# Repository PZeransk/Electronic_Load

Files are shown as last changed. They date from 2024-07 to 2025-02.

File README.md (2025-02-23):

# Electronic_Load

The aim of this project is to design high power (around 200W) electronic load. It will be developed on STM32 uC. Whole repository will feature electronic schematic, PCB and code.

### Used external libralies
https://github.com/afiskon/stm32-ssd1306

### Current problems

I have encoutered two issues with my PCB design:
* Wrong D4 pinout, pins are mixed so diode does not conduct any current 
* Nucleo connectors are moved 2.54 mm to the side

Both will be fixed in another PCB revision.

### Differences between schematic and PCB

To ease further prototyping I made following changes:
* Instead of 4 1 Ohm resistor I used one 12 Ohm to lower the maximum current,
* Used only one NMOS, that is because the current will be lower now and if something breaks, it will be cheaper to replace,
* Shorted every potentiometer, they are supposed to be used for voltage compensation, but during this stage of prototyping they will be useless,
* In place of D4 I used random 1N4007 diode to keep reverse polarity protection,
* Removed eFuse, because it didn't work correctly (I hope Murphy didn't get it).

Changes may be obsereved on the photo below.

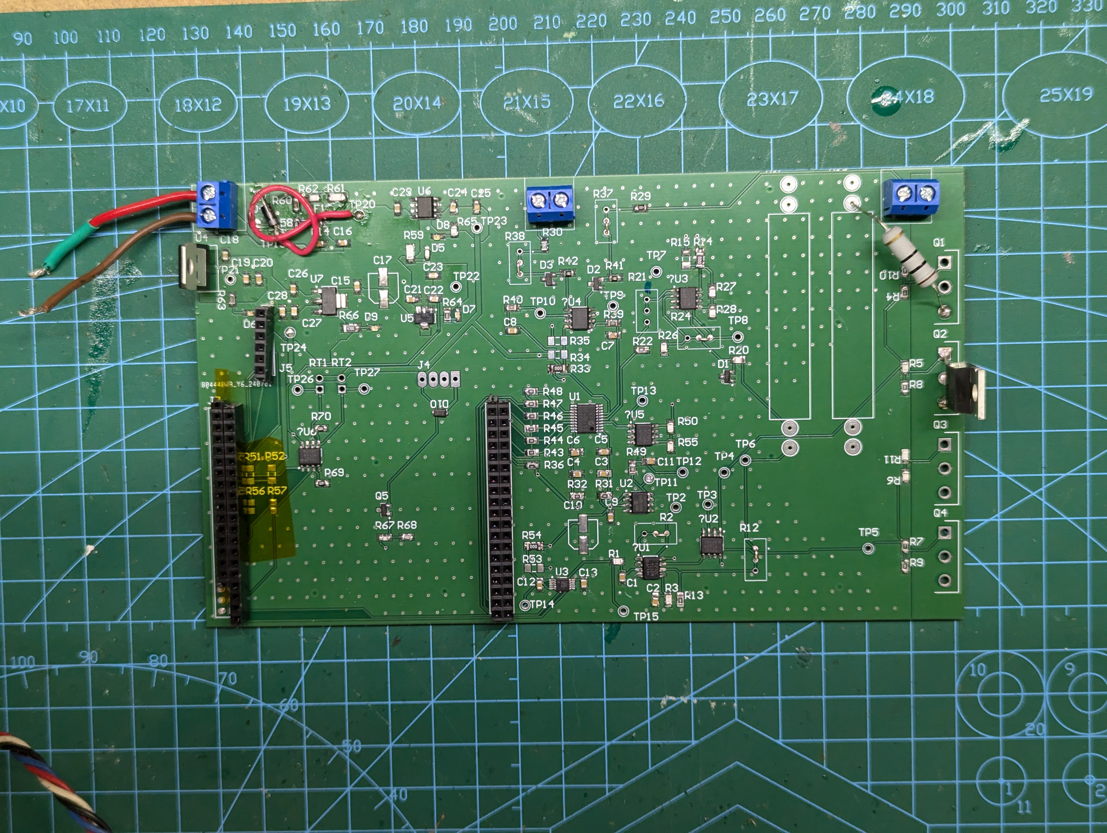
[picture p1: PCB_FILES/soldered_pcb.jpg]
Soldered PCB photo


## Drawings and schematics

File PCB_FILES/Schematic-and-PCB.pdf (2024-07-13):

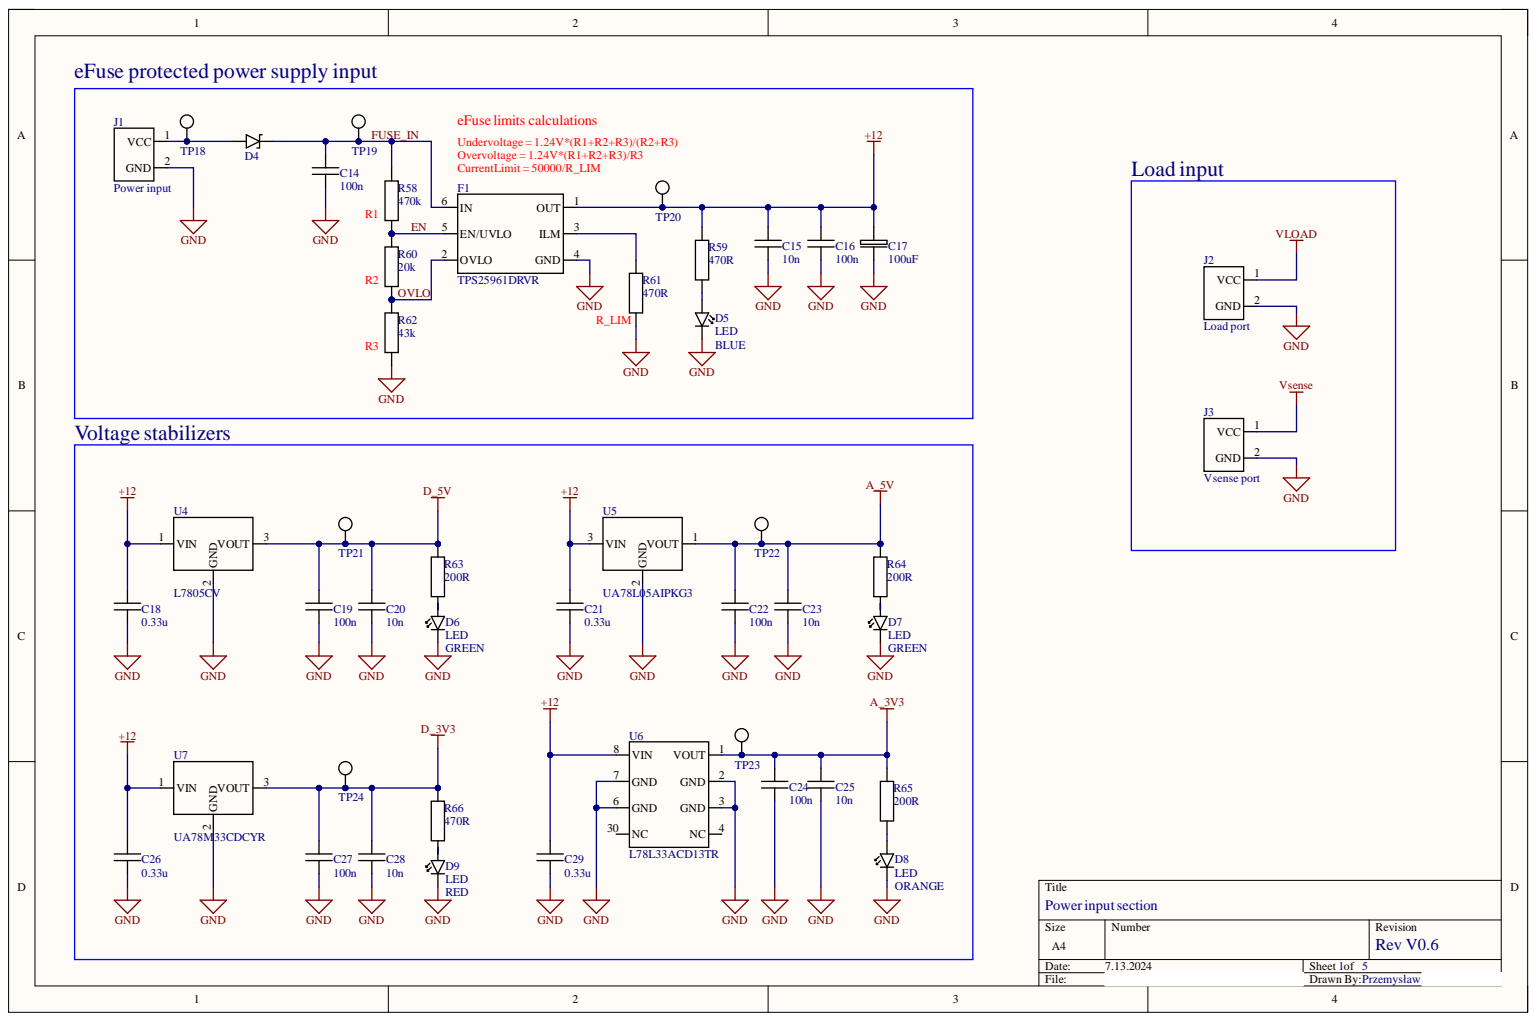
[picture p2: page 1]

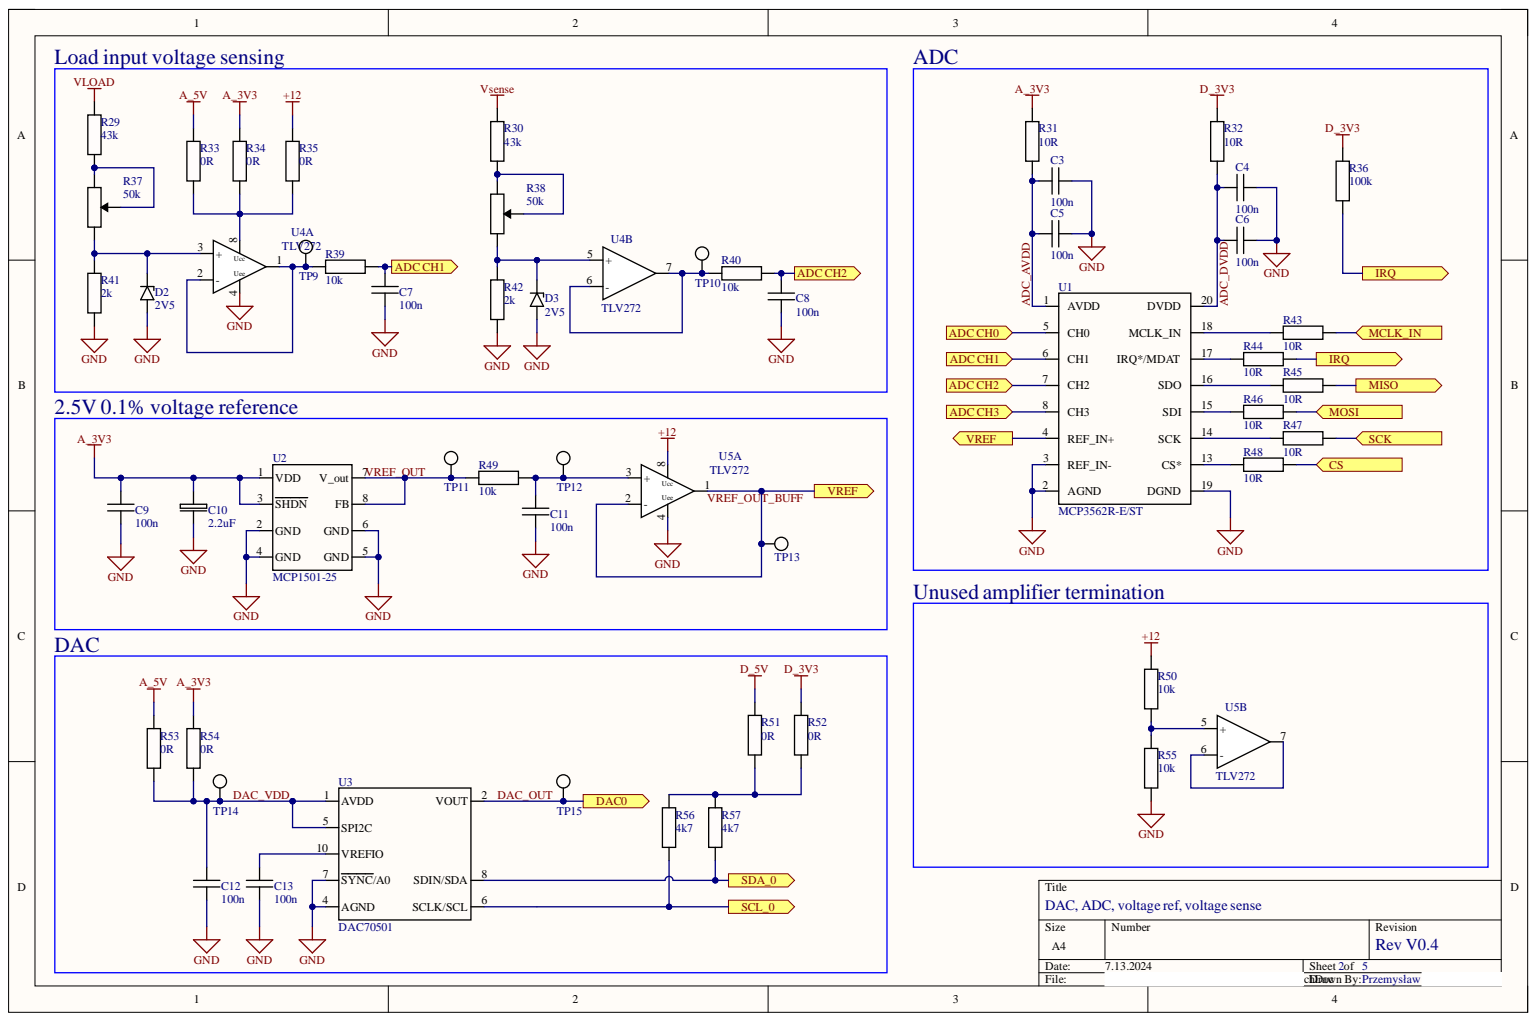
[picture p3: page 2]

Title
DAC, ADC, voltage ref, voltage sense

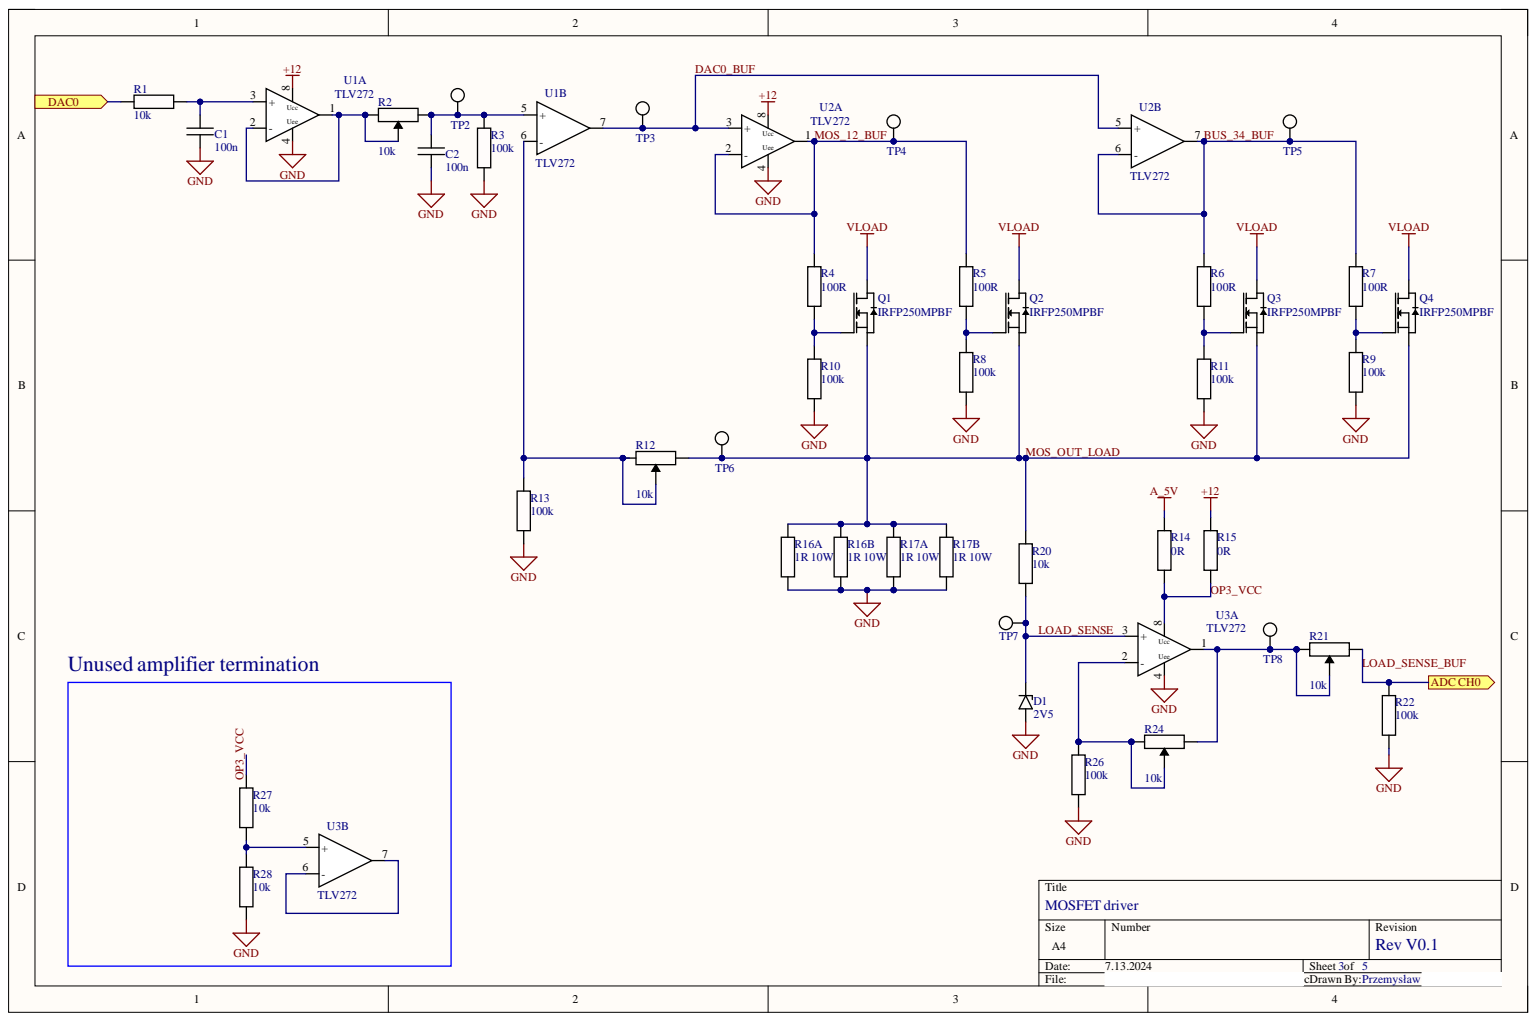
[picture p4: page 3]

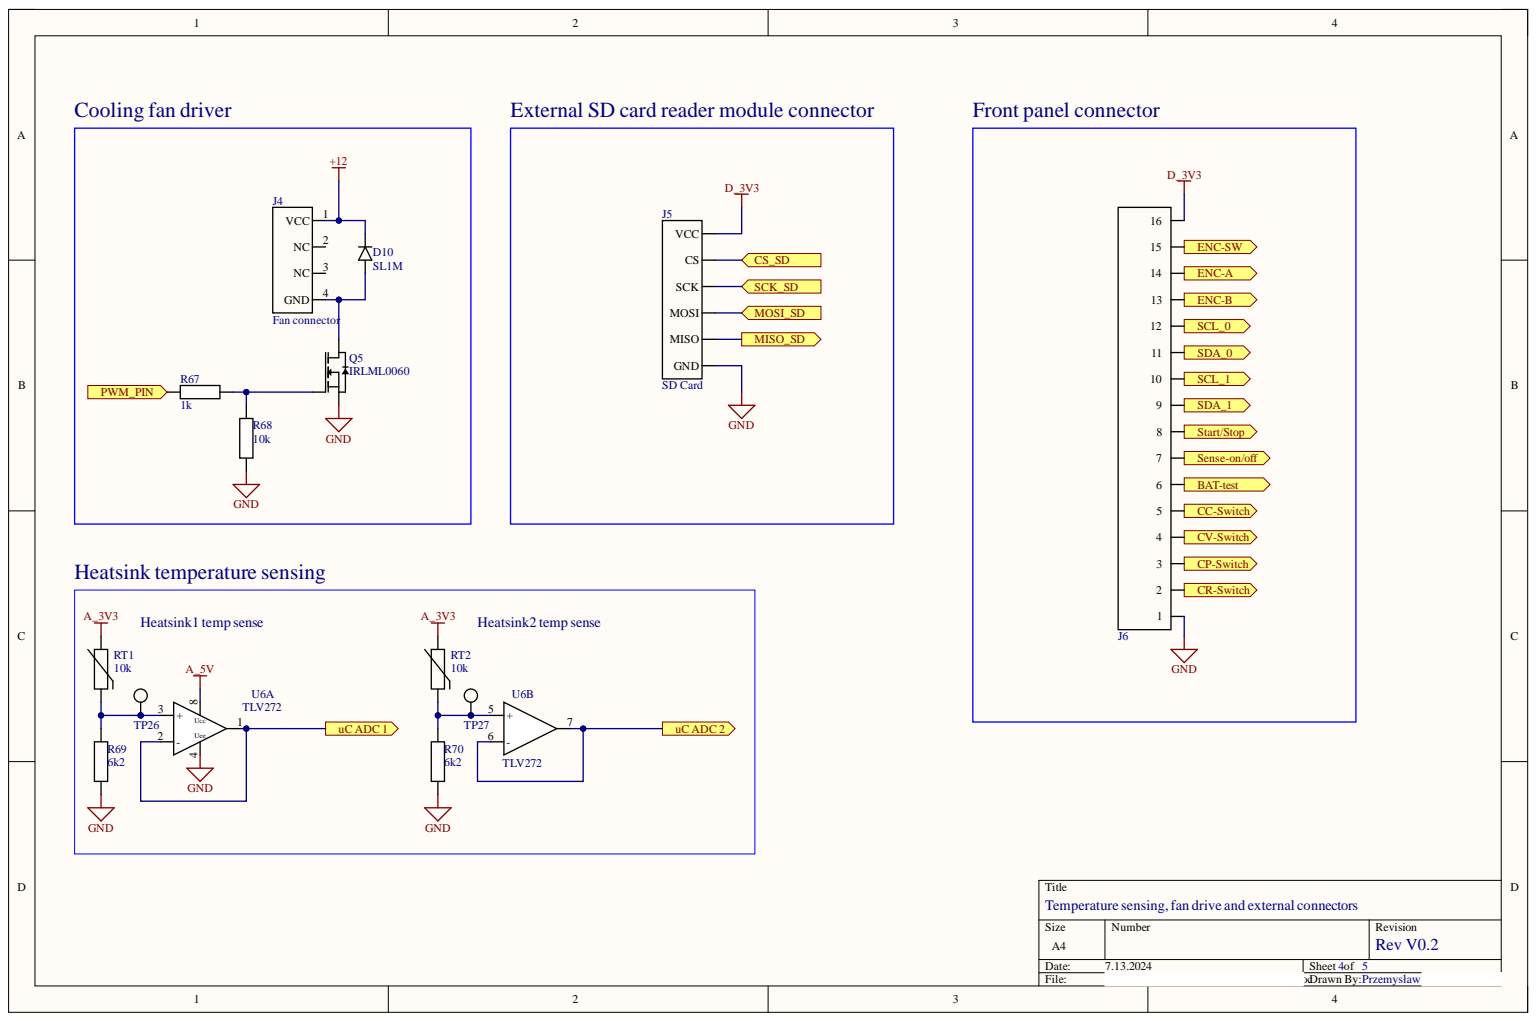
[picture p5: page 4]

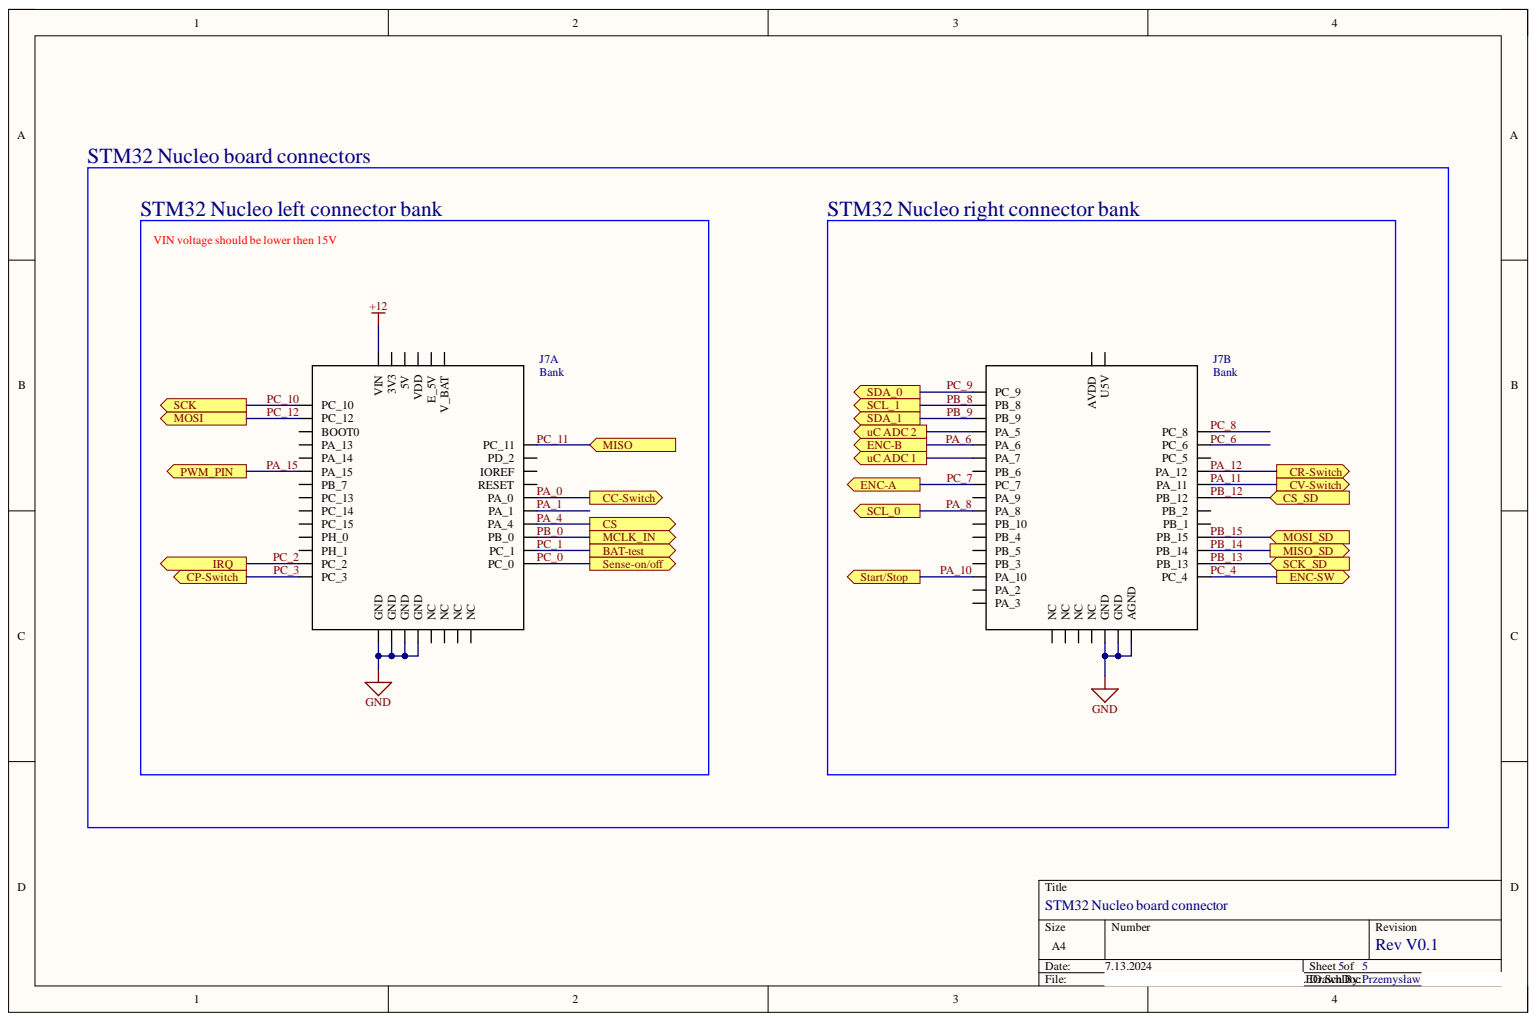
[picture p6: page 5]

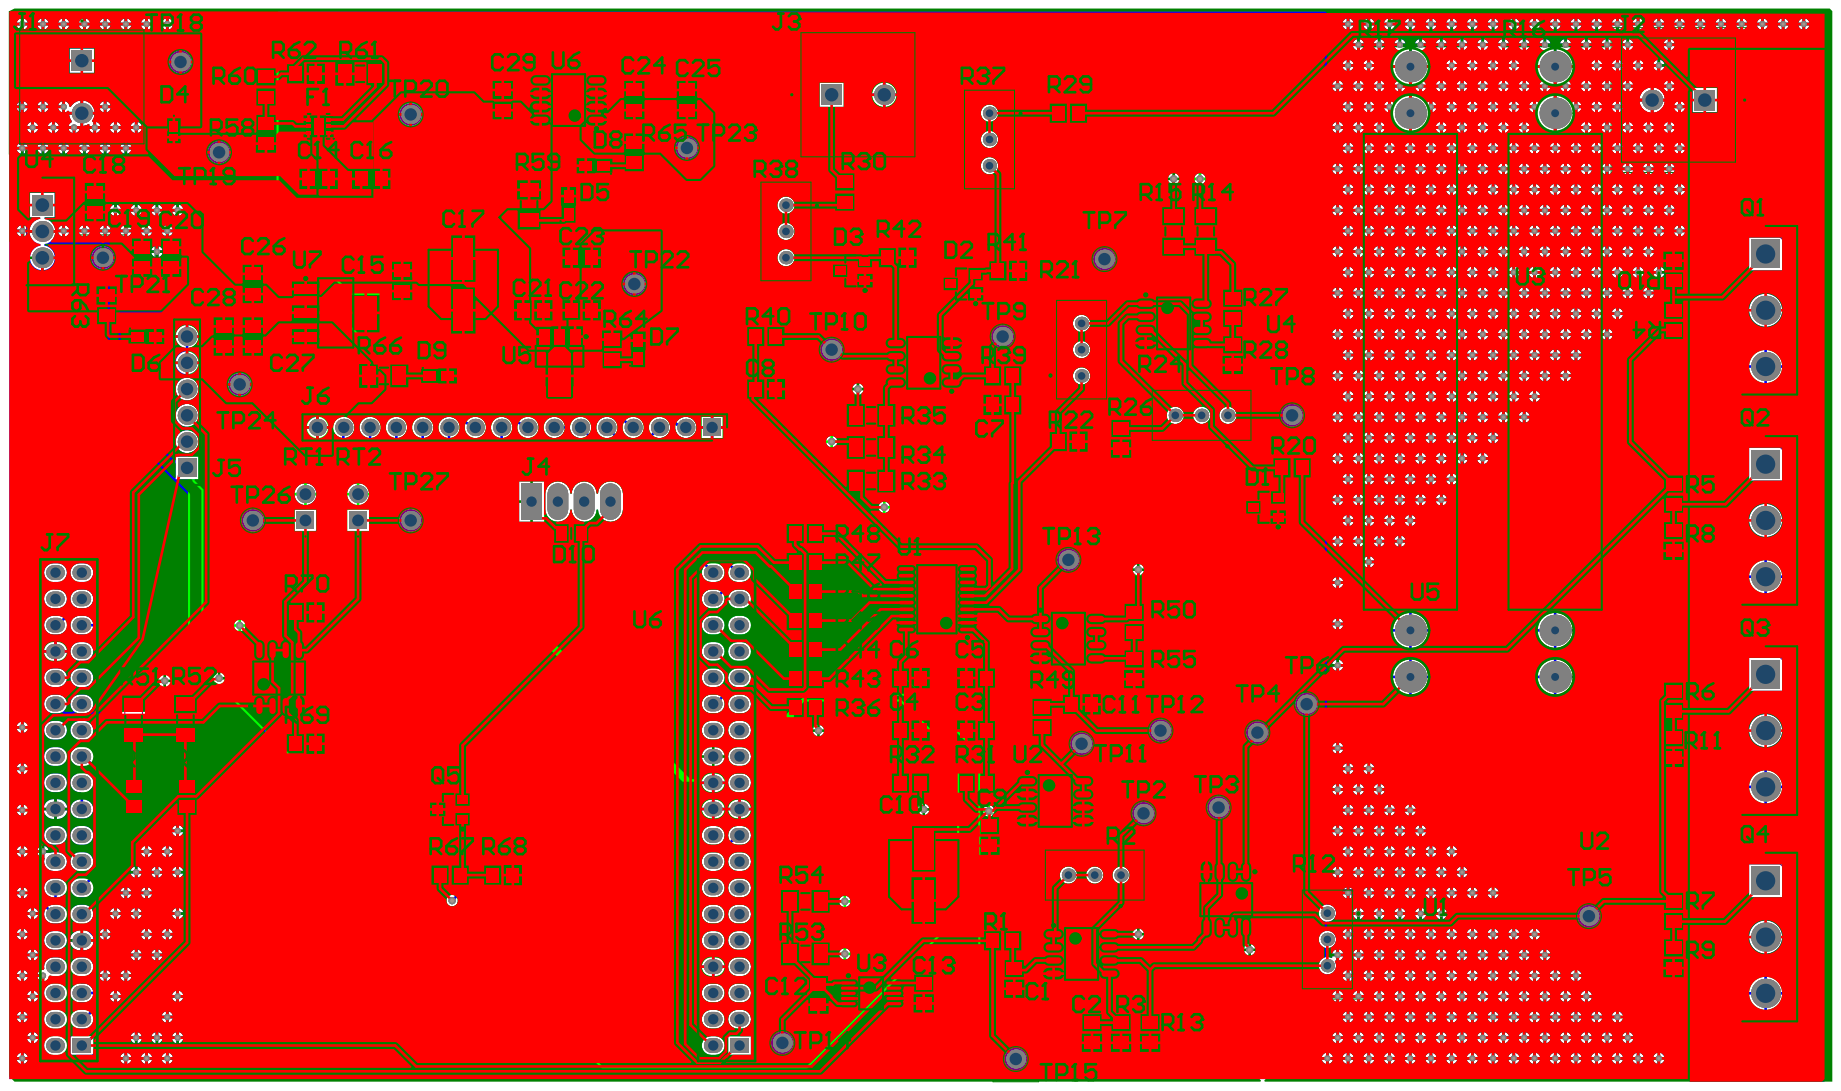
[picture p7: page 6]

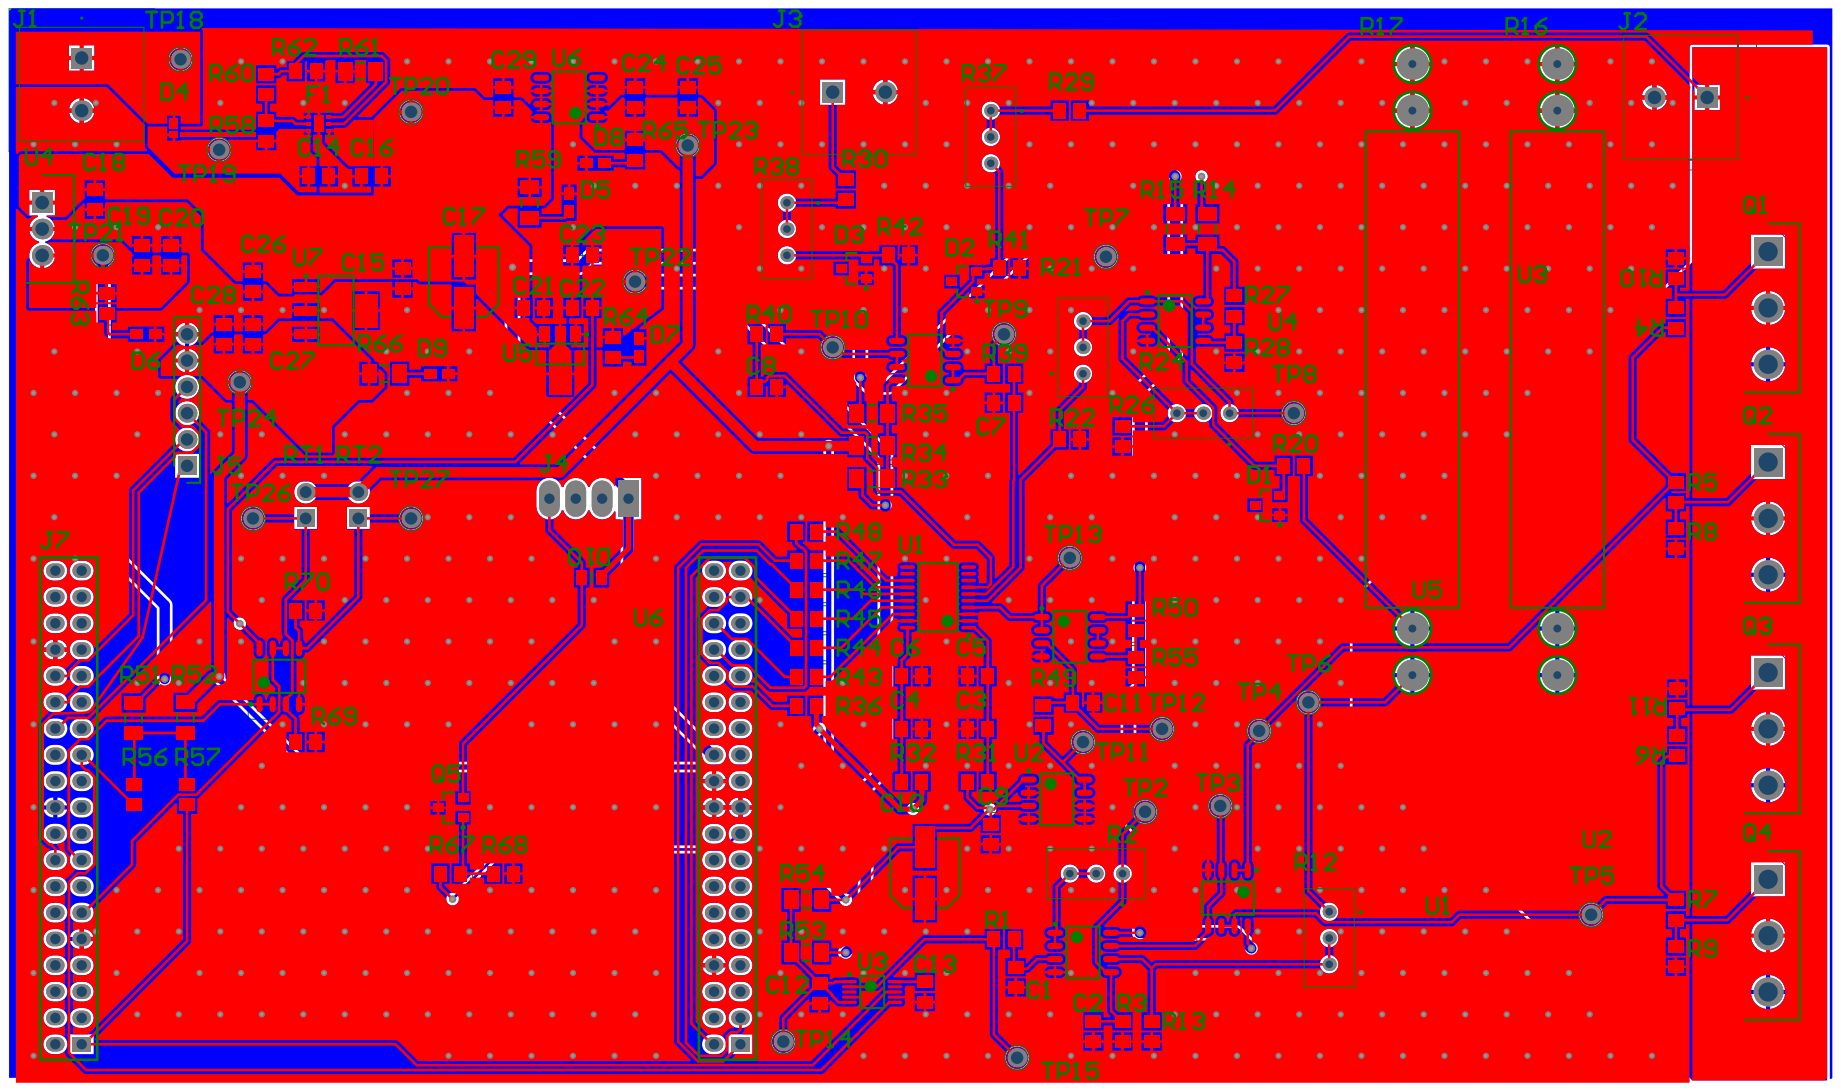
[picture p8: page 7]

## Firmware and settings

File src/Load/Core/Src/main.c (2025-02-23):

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
/* Includes ------------------------------------------------------------------*/
#include "main.h"
#include "adc.h"
#include "dma.h"
#include "i2c.h"
#include "spi.h"
#include "tim.h"
#include "usart.h"
#include "gpio.h"

/* USER CODE BEGIN Includes */
#include "menu.h"
#include "functions.h"
#include "DAC70501.h"
/* USER CODE END Includes */

/* USER CODE BEGIN PD */
#define menuCount 3
/* USER CODE END PD */


/* USER CODE BEGIN PV */
I2C_HandleTypeDef hi2c1;
uint8_t pulses = 0;
uint8_t positions = 0;
/* USER CODE END PV */

void SystemClock_Config(void);
/* USER CODE BEGIN 0 */

// define menus
menu CCMenu;
menu CVMenu;
menu CPMenu;
menu CRMenu;
menu BatMenu;


menu menuArray[menuCount]; // there are 4 menus

uint8_t toggles = 0;
uint8_t modToggles = 0;
uint8_t encToggles = 0;
uint8_t setPosition = 0;
uint8_t changeSetToggles = 0;

uint8_t arraySize=0;
bool wasToggled = false;
bool startStop = false;
bool setMode = false;


/* USER CODE END 0 */

/**
  * @brief  The application entry point.
  * @retval int
  */
int main(void)
{
  /* MCU Configuration--------------------------------------------------------*/

  /* Reset of all peripherals, Initializes the Flash interface and the Systick. */
  HAL_Init();

  /* Configure the system clock */
  SystemClock_Config();

  /* Initialize all configured peripherals */
  MX_GPIO_Init();
  MX_USART2_UART_Init();
  MX_I2C1_Init();
  MX_SPI2_Init();
  MX_DMA_Init();
  MX_TIM1_Init();
  MX_TIM3_Init();
  MX_ADC1_Init();
  MX_I2C3_Init();
  MX_SPI3_Init();
  /* USER CODE BEGIN 2 */

  HAL_TIM_Encoder_Start(&htim3, TIM_CHANNEL_ALL);

  ssd1306_Init();
  ssd1306_SetCursor(8, 10);
  ssd1306_WriteString("ELECTRTONIC LOAD", Font_7x10, White);
  ssd1306_SetCursor(14, 20);
  ssd1306_WriteString("Ver. V0.0", Font_11x18, White);
  ssd1306_SetCursor(46, 38);
  ssd1306_WriteString("Author", Font_6x8, White);
  ssd1306_SetCursor(40, 46);
  ssd1306_WriteString("PZERANSK", Font_6x8, White);
  ssd1306_UpdateScreen();

  //ssd1306_Fill(Black);
  initStruct(&CCMenu, "CC Mode", "Set I:", "U in:", "Power:");
  initStruct(&CVMenu, "CV Mode", "Set U:", "Power:", "I in:");
  initStruct(&CPMenu, "CP Mode", "Set P:", "Power:", "x");
  initStruct(&CRMenu, "CR Mode", "Set R:", "Power:", "x");
  initStruct(&BatMenu, "BAT Test", "Set I:", "Set U", "Capacity");
  menuArray[0]=CCMenu;
  menuArray[1]=CPMenu;
  menuArray[2]=BatMenu;
  //menuArray[2]=CVMenu;
  //menuArray[3]=CRMenu;
  strcpy(menuArray[0].val_line1,"01000");
  strcpy( menuArray[1].val_line1,"010");
  HAL_Delay(2000);
  //displayMenu(&CCMenu);



  /* USER CODE END 2 */

  /* Infinite loop */
  /* USER CODE BEGIN WHILE */

  while (1)
  {
    ssd1306_Fill(Black);

    checkLongPress(GPIOC, SET_Mode_Pin, &setMode, &changeSetToggles);

	modToggles = toggles%menuCount;
	menuArray[modToggles].status = startStop;
	pulses = TIM3->CNT;
	positions = pulses/2;
	if(setMode){
		if(strncmp(menuArray[modToggles].measVal1,"Set x:",4)==0){

			if(changeSetToggles%2==0){

				arraySize = sizeof(menuArray[modToggles].val_line1)/sizeof(*menuArray[modToggles].val_line1);
				setPosition = encToggles%(arraySize);
				ssd1306_Line(42+7*setPosition, 28, 42+7*setPosition+7, 28, White);
				menuArray[modToggles].val_line1[setPosition] = positions%10+'0';

			}else if(changeSetToggles%2==1){

			    arraySize = sizeof(menuArray[modToggles].val_line2)/sizeof(*menuArray[modToggles].val_line2);
				setPosition = encToggles%(arraySize);
				ssd1306_Line(42+7*setPosition, 38, 42+7*setPosition+7, 38, White);
				menuArray[modToggles].val_line2[setPosition] = positions%10+'0';

			}
		}else{
		    arraySize = sizeof(menuArray[modToggles].val_line1)/sizeof(*menuArray[modToggles].val_line1);
			setPosition = encToggles%(arraySize);
			ssd1306_Line(42+7*setPosition, 28, 42+7*setPosition+7, 28, White);
			menuArray[modToggles].val_line1[setPosition] = positions%10+'0';
		}


	}

	if(strcmp(menuArray[modToggles].menuName, CCMenu.menuName) == 0 && ChangeArrayToInt(menuArray[modToggles].val_line1, arraySize)>10000){
		strcpy(menuArray[modToggles].val_line1,"10000");
	}else if(strcmp(menuArray[modToggles].menuName, CPMenu.menuName) == 0 && ChangeArrayToInt(menuArray[modToggles].val_line1, arraySize)>200){
		strcpy(menuArray[modToggles].val_line1,"200");
	}


	displayMenu(&menuArray[modToggles]);


	//HAL_GPIO_WritePin(GPIOA, GPIO_PIN_5, 0);
	//HAL_Delay(200);
	//HAL_GPIO_WritePin(GPIOA, GPIO_PIN_5, 1);
	//HAL_Delay(200);

    /* USER CODE END WHILE */

    /* USER CODE BEGIN 3 */
  }
  /* USER CODE END 3 */
}

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
/* USER CODE BEGIN 4 */
void HAL_GPIO_EXTI_Callback(uint16_t GPIO_Pin){
	if(GPIO_Pin == B1_Pin && !(startStop || setMode)){
		toggles++;
	}

	if(GPIO_Pin == StopStart_Pin){
		startStop = !startStop;
	}

	//if(GPIO_Pin == SET_Mode_Pin){
	//	setMode = !setMode;
	//}

	if(GPIO_Pin == EncoderSwitch_Pin && setMode){
		encToggles++;
		TIM3->CNT = 0;
	}
}
/* USER CODE END 4 */
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


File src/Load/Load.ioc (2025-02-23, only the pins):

Mcu.UserName=STM32F411RETx
PA0-WKUP.Signal=ADCx_IN0
PA1.Signal=ADCx_IN1
PA13.GPIO_Label=TMS
PA13.Signal=SYS_JTMS-SWDIO
PA14.GPIO_Label=TCK
PA14.Signal=SYS_JTCK-SWCLK
PA2.GPIO_Label=USART_TX
PA2.Signal=USART2_TX
PA3.GPIO_Label=USART_RX
PA3.Signal=USART2_RX
PA4.Signal=SPI3_NSS
PA5.GPIO_Label=LD2 [Green Led]
PA5.Signal=GPIO_Output
PA6.GPIO_Label=Encoder1
PA6.Signal=S_TIM3_CH1
PA7.Signal=TIM1_CH1N
PA8.Signal=I2C3_SCL
PA9.Signal=S_TIM1_CH2
PB0.GPIO_Label=MCLK
PB0.Signal=GPIO_Output
PB12.Signal=SPI2_NSS
PB13.Signal=SPI2_SCK
PB14.Signal=SPI2_MISO
PB15.Signal=SPI2_MOSI
PB3.GPIO_Label=SWO
PB3.Signal=SYS_JTDO-SWO
PB8.Signal=I2C1_SCL
PB9.Signal=I2C1_SDA
PC0.GPIO_Label=StopStart
PC0.Signal=GPXTI0
PC1.GPIO_Label=SET_Mode
PC1.Signal=GPIO_Input
PC10.Signal=SPI3_SCK
PC11.Signal=SPI3_MISO
PC12.Signal=SPI3_MOSI
PC13-ANTI_TAMP.GPIO_Label=B1 [Blue PushButton]
PC13-ANTI_TAMP.Signal=GPXTI13
PC14-OSC32_IN.Signal=RCC_OSC32_IN
PC15-OSC32_OUT.Signal=RCC_OSC32_OUT
PC2.GPIO_Label=IRQ
PC2.Signal=GPXTI2
PC4.GPIO_Label=EncoderSwitch
PC4.Signal=GPXTI4
PC7.GPIO_Label=Encoder2
PC7.Signal=S_TIM3_CH2
PC9.Signal=I2C3_SDA

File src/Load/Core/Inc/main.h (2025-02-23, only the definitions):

#define B1_Pin GPIO_PIN_13
#define B1_GPIO_Port GPIOC
#define B1_EXTI_IRQn EXTI15_10_IRQn
#define StopStart_Pin GPIO_PIN_0
#define StopStart_GPIO_Port GPIOC
#define StopStart_EXTI_IRQn EXTI0_IRQn
#define SET_Mode_Pin GPIO_PIN_1
#define SET_Mode_GPIO_Port GPIOC
#define IRQ_Pin GPIO_PIN_2
#define IRQ_GPIO_Port GPIOC
#define USART_TX_Pin GPIO_PIN_2
#define USART_TX_GPIO_Port GPIOA
#define USART_RX_Pin GPIO_PIN_3
#define USART_RX_GPIO_Port GPIOA
#define LD2_Pin GPIO_PIN_5
#define LD2_GPIO_Port GPIOA
#define Encoder1_Pin GPIO_PIN_6
#define Encoder1_GPIO_Port GPIOA
#define EncoderSwitch_Pin GPIO_PIN_4
#define EncoderSwitch_GPIO_Port GPIOC
#define EncoderSwitch_EXTI_IRQn EXTI4_IRQn
#define MCLK_Pin GPIO_PIN_0
#define MCLK_GPIO_Port GPIOB
#define Encoder2_Pin GPIO_PIN_7
#define Encoder2_GPIO_Port GPIOC
#define TMS_Pin GPIO_PIN_13
#define TMS_GPIO_Port GPIOA
#define TCK_Pin GPIO_PIN_14
#define TCK_GPIO_Port GPIOA
#define SWO_Pin GPIO_PIN_3
#define SWO_GPIO_Port GPIOB

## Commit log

2022-07-18 Added basic encoder and OLED test
2022-07-21 Started work on Constant Current Menu
2022-08-31 Fixed switching between menus
2022-09-01 Added more menu selectable via buttons
2022-09-03 PWM output now works in CC & BAT modes
2022-10-22 Started work on SPI communication
2022-10-22 SPI communication with MCP4921 should be working
2022-11-21 Added PCB files
    [Electronic Load.PrjPcb, Schematic.SchDoc, Sheet1.SchDoc]
2024-02-15 Moved project to STM32 platform
2024-02-15 Removed PCB files
    [Electronic Load.PrjPcb, Schematic.SchDoc, Sheet1.SchDoc]
2024-02-16 Mode switching is locked while channel is on
2024-02-18 Locking setting current over desired value works
2024-02-25 Added dual functionality to set-mode button
    Also reserved ports for ADC
2024-07-13 Added schematic and PCB layout
2024-09-05 Added soldered PCB photo

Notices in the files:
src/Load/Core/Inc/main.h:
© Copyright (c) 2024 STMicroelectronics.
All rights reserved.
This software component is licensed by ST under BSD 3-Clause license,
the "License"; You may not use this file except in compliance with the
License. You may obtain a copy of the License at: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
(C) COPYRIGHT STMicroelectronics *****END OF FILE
